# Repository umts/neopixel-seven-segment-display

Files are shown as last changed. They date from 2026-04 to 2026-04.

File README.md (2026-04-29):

# Neopixel Seven Segment Display
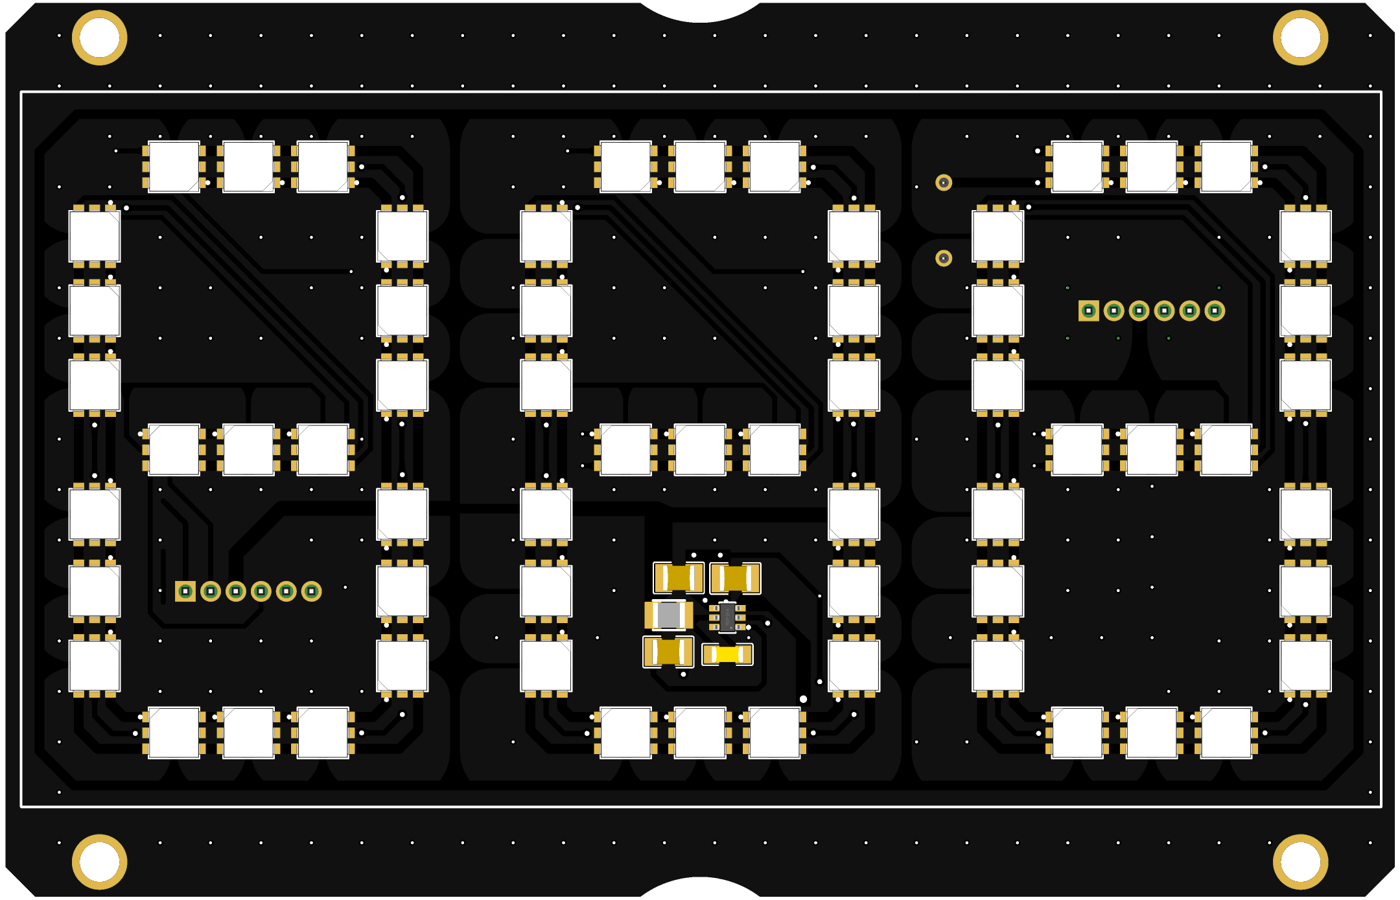
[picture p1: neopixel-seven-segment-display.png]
Neopixel Seven Segment Display


A large, daisy chain-able, 3 digit seven-segment display board.

## Design
Constructed with [WS2813B-V5](https://media.digikey.com/pdf/Data%20Sheets/Seeed%20Technology/WS2813B_Ver.V5_10-20-19.pdf) "Intelligent control LED integrated light source[s]", there's no need for additional decoupling capacitors, reducing complexity.

The WS2813B-V5s include dual-signal wires (signal and backup signal) so any one pixel’s failure won't affect signal transfer.

## Features
- 63 total WS2813B-V5 LED pixels
- 3 WS2813B-V5 LED pixels per segment
- 2 6-pin spring clamp connectors
- 2A, 5V fixed output, synchronous buck converter with a wide input voltage range of 3.8V to 32V
- Backup NZR data signal to ground jumper pins

## Connector(s) Pinout
### H1
Pin | Function | I/O (Input/Output)
--- | --- | ---
VCC | Power (Switched) | I/O
EN | Buck converter Enable | I
DI | NZR Data Signal | I
5V | Fixed 5V supply | I/O
BI | Backup NZR Data Signal | I
GND | Ground Connection | I/O

### H2
Pin | Function | I/O (Input/Output)
--- | --- | ---
VCC | Power (Switched) | I/O
EN | Buck converter Enable | I
DO | NZR Data Signal | O
5V | Fixed 5V supply | I/O
BO | Backup NZR Data Signal | O
GND | Ground Connection | I/O

### J1
Pin | Function | I/O (Input/Output)
--- | --- | ---
BI | Backup NZR Data Signal | I
GND | Ground Connection | I/O

## Usage
- When powering a display with 5V the VCC pin can be left disconnected.
- Drive EN high to turn on the regulator and low to turn it off. Attach to VCC or leave open for automatic startup.
- The first display in any chain should have BI pulled to ground, this can be achieved by setting the J1 switch to ON

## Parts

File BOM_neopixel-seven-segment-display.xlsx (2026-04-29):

No. | Quantity | Comment | Designator | Footprint | Value | Manufacturer Part | Manufacturer | Supplier Part | Supplier
1 | 1 | 10uF | C1 | C1210 | 10uF | CL32B106KAJNNNE | SAMSUNG(三星) | C39232 | LCSC
2 | 1 | 100nF | C2 | C1206 | 100nF | 1206N104J500CT | Walsin(华新科) | C170182 | LCSC
3 | 2 | 22uF | C3,C4 | C1210 | 22uF | CL32B226KAJNNNE | SAMSUNG(三星) | C309062 | LCSC
4 | 2 | DB2EVC-2.54-6P-GN | H1,H2 | CONN-TH_6P-P2.54_DIBO_DB2EVC-2.54-6P-GN |  | DB2EVC-2.54-6P-GN | DORABO(地博电气) | C2927497 | LCSC
5 | 1 | DSWB01LHGET | J1 | SW-TH_DSWB01LHGET |  | DSWB01LHGET | YE | C126888 | LCSC
6 | 1 | 4.7uH | L1 | IND-SMD_L3.2-W2.5_CMI3225XX | 4.7uH | DFE322520FD-4R7M=P2 | muRata(村田) | C2045343 | LCSC
7 | 63 | WS2813B-V5 | LED1,LED2,LED3,LED4,LED5,LED6,LED7,LED8,LED9,LED10,LED11,LED12,LED13,LED14,LED15,LED16,LED17,LED18,LED19,LED20,LED21,LED22,LED23,LED24,LED25,LED26,LED27,LED28,LED29,LED30,LED31,LED32,LED33,LED34,LED35,LED36,LED37,LED38,LED39,LED40,LED41,LED42,LED43,LED44,LED45,LED46,LED47,LED48,LED49,LED50,LED51,LED52,LED53,LED54,LED55,LED56,LED57,LED58,LED59,LED60,LED61,LED62,LED63 | LED-SMD_6P-L5.0-W5.0-TL |  | WS2813B-V5 | worldsemi | C965558 | LCSC
8 | 1 | AP63205WU-7 | U2 | TSOT-23-6_L2.9-W1.6-P0.95-LS2.8-BL |  | AP63205WU-7 | DIODES(美台) | C2071056 | LCSC

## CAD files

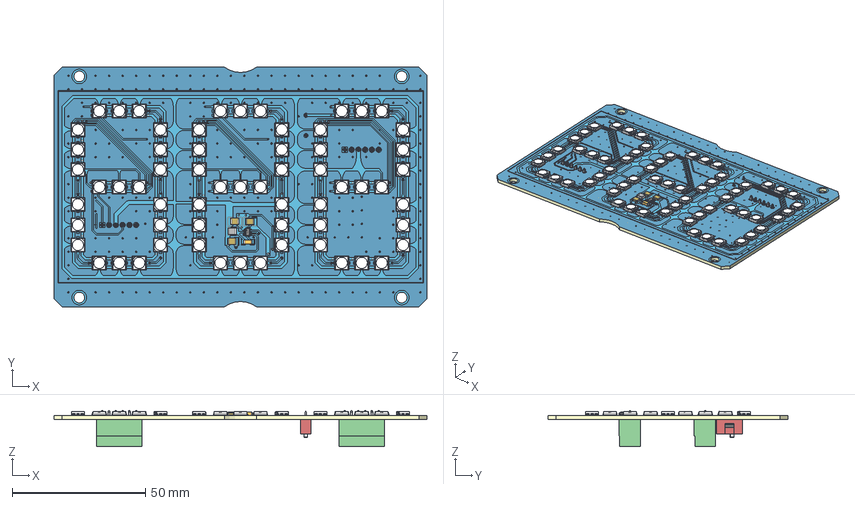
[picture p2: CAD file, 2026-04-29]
3D_neopixel-seven-segment-display.step
140.0 x 90.0 x 13.6 mm
Board~6cs7
TopCopper~6cs7
BottomCopper~6cs7
TopSilkscreen~6cs7
BottomSilkscreen~6cs7
TopFpcStiffener~6cs7
BottomFpcStiffener~6cs7
C1210~C1210_L3.2-W2.5-H0.9~6cs7 x 3
SW-TH_DSWB01LHGET~SW-TH_2P-L4.1-W9.9-H5.4-P2.54~6cs7
LED-SMD_6P-L5.0-W5.0-TL~LED5060-6P_L5.0-W5.0-LS5.3~6cs7 x 63
CONN-TH_6P-P2.54_DIBO_DB2EVC-2.54-6P-GN~CONN-TH_6P-P2.54_DIBO_ DB2EVC-2.54-6P-GN~6cs7 x 2
C1206~C1206_L3.2-W1.6-H1.3~6cs7
IND-SMD_L3.2-W2.5_CMI3225XX~IND-SMD_L3.2-W2.5-H1.3_CMI3225XX~6cs7
TSOT-23-6_L2.9-W1.6-P0.95-LS2.8-BL~TSOT-23-6_ L2.9-W1.6-H1.1-LS2.8-P0.95~6cs7

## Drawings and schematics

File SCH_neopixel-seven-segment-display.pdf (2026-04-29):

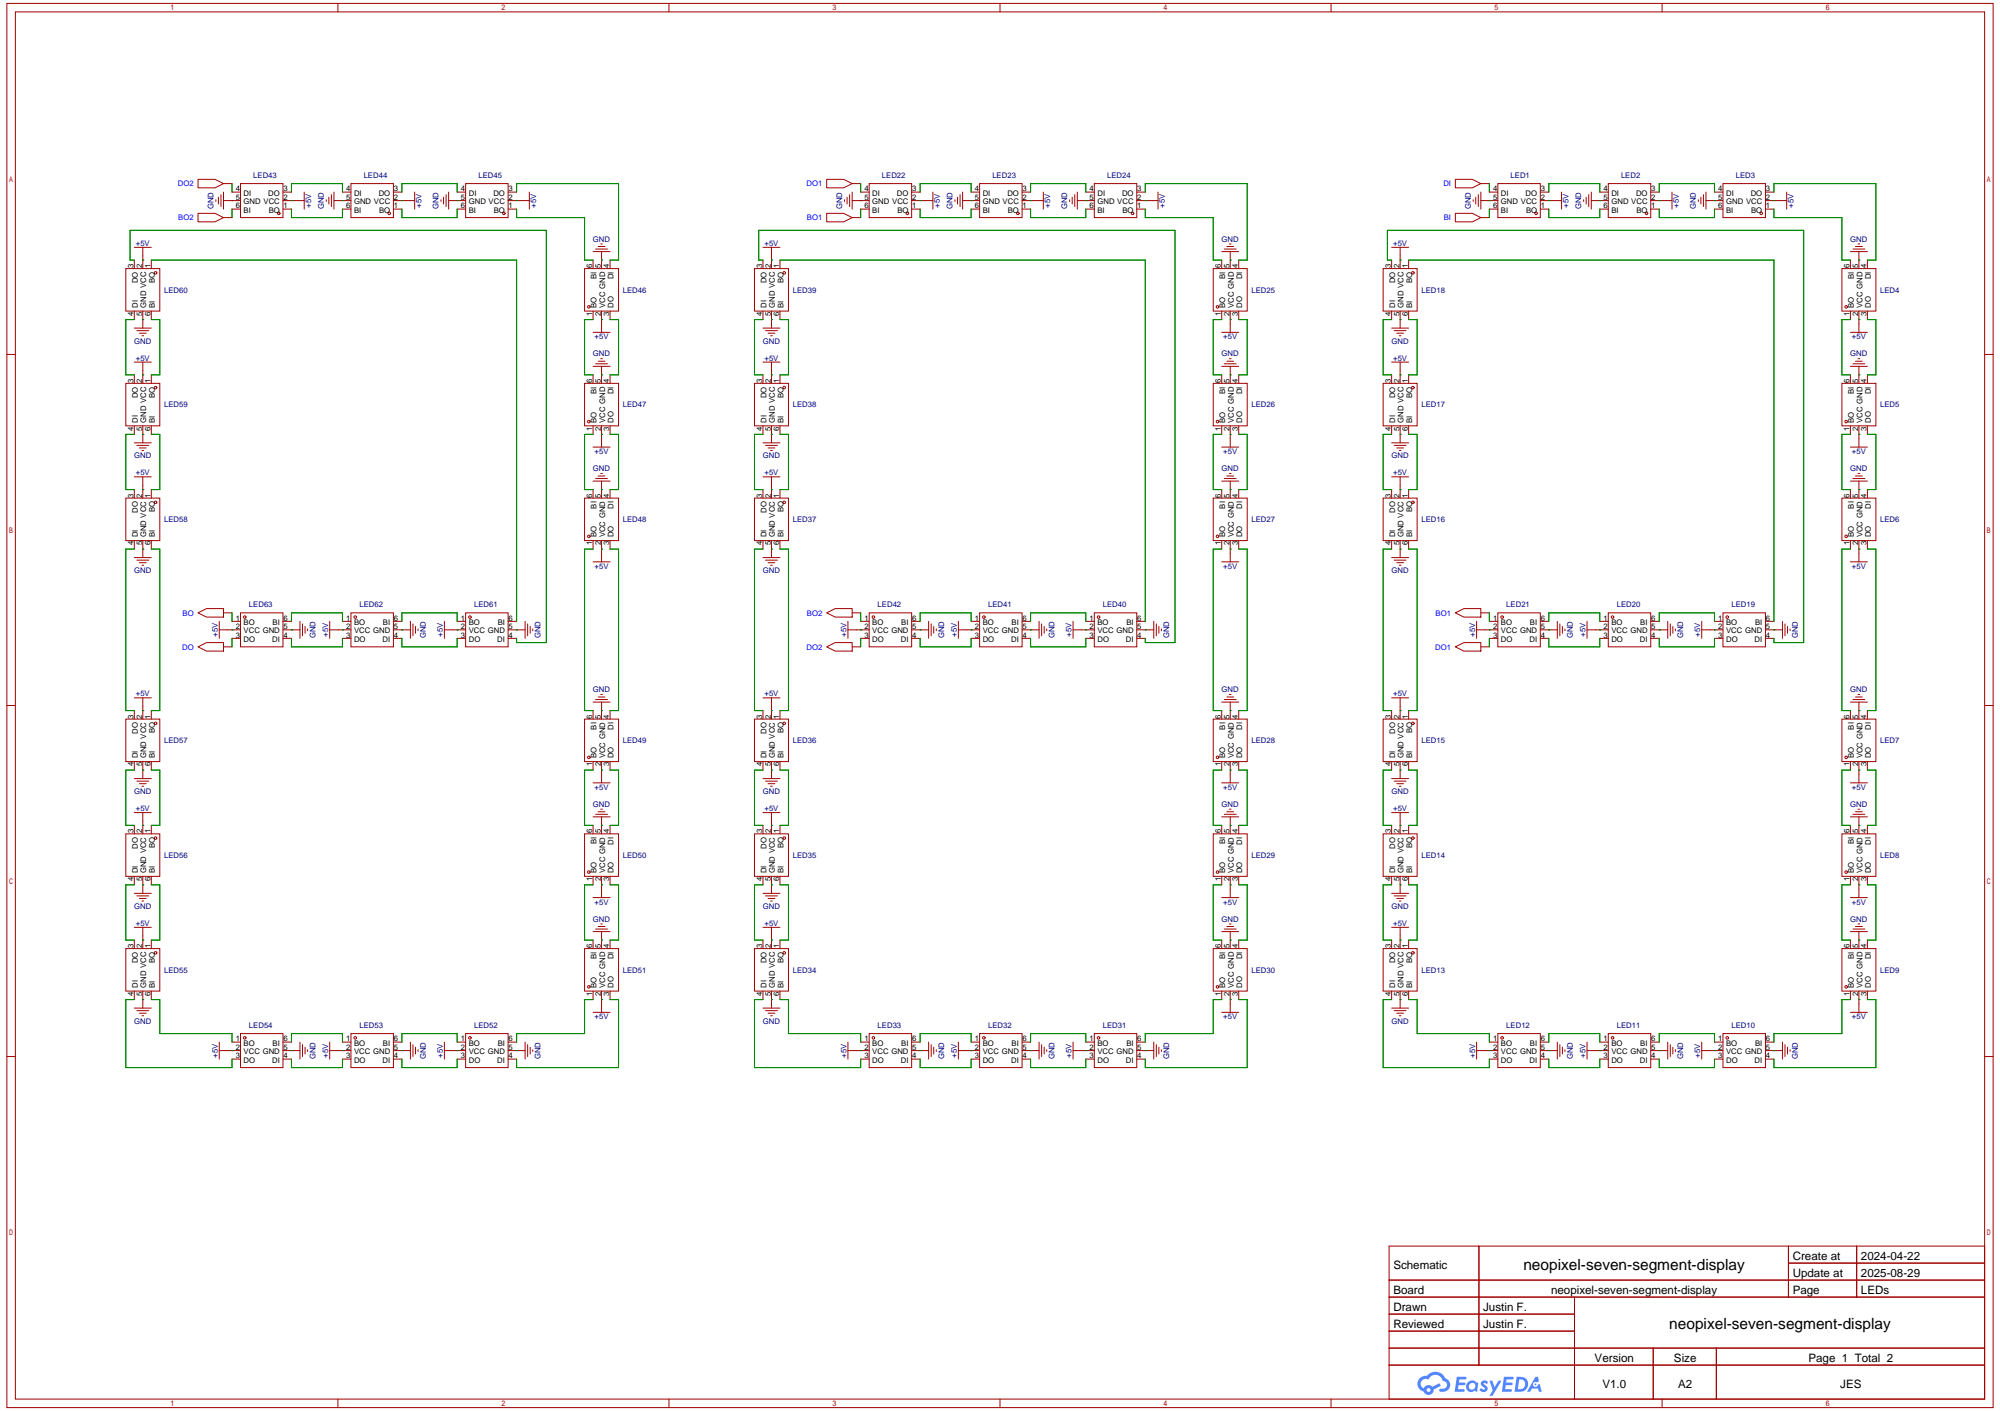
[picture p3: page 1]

Schematic | neopixel-seven-segment-display | Create at | 2024-04-22

Board | neopixel-seven-segment-display | Page | LEDs
Drawn | Justin F. | neopixel-seven-segment-display
Reviewed | Justin F.

Update at | 2025-08-29

Version | Size | Page 1 Total 2
V1.0 | A2 | JES

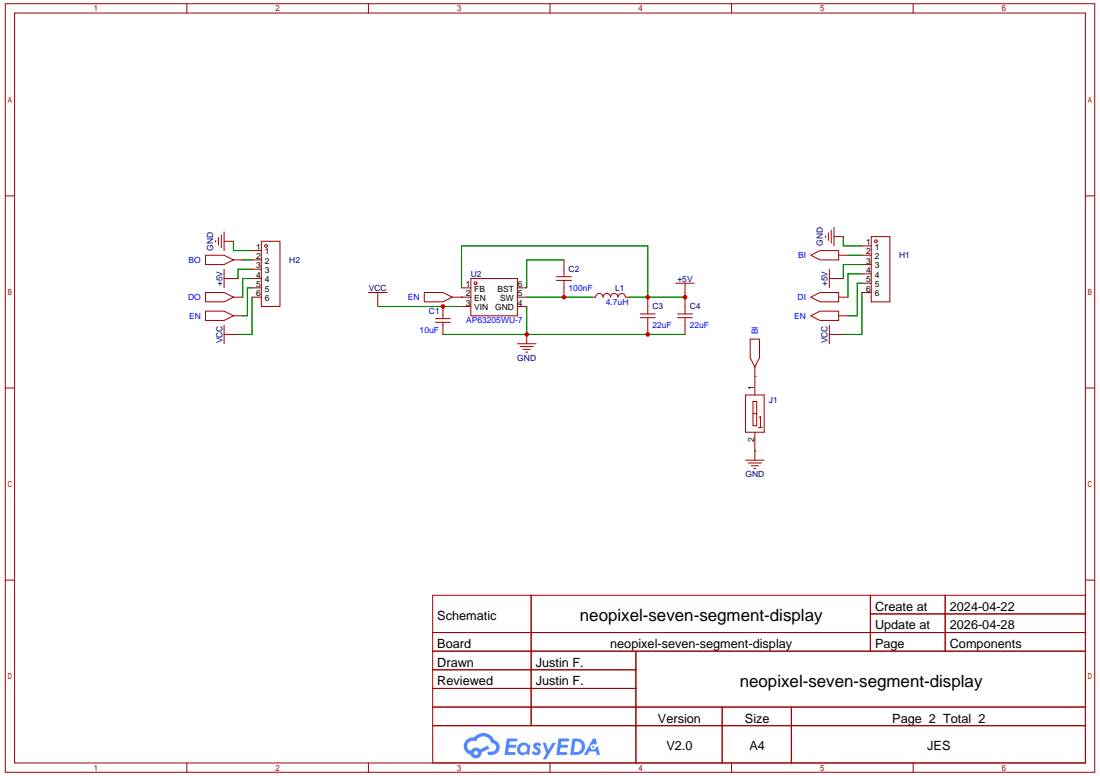
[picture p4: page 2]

Schematic | neopixel-seven-segment-display | Create at | 2024-04-22

Update at | 2026-04-28

Board | neopixel-seven-segment-display | Page | Components
Drawn | Justin F. | neopixel-seven-segment-display
Reviewed | Justin F.

Version | Size | Page 2 Total 2
V2.0 | A4 | JES

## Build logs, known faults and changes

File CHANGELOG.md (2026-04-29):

# Changelog

All notable changes to this project will be documented in this file.

The format is based on [Keep a Changelog](https://keepachangelog.com/en/1.1.0/),
and this project adheres to [Semantic Versioning](https://semver.org/spec/v2.0.0.html).

## [Unreleased]

## [2.0] - 2026-04-29

### Changed

- Replaced H1 and H2 connectors
  - From spring clamp to terminal block
- Replaced J1 jumper pins with dip switch
- Updated silk screen
- Trace/pour routing (minor)
- Synced parts properties with LCSC

[unreleased]: https://github.com/umts/neopixel-seven-segment-display/compare/v2.0...main
[2.0]: https://github.com/umts/neopixel-seven-segment-display/compare/v1.0...v2.0

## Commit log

2025-08-29 Add README, update 3D models, edited silkscreen
    [BOM_departure_board_display.xlsx, BOM_neopixel-seven-segment-display.xlsx, PickAndPlace_neopixel-seven-segment-display.xlsx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]
2026-04-29 Revision 2
    [3D_neopixel-seven-segment-display.step, BOM_neopixel-seven-segment-display.xlsx, PickAndPlace_neopixel-seven-segment-display.xlsx]
